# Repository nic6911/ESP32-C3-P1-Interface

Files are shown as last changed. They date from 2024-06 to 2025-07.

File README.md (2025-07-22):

# ESP32-C3-P1-Interface
ESPHome module for P1 port power meter readings for use with Home Assistant.
Code is based on Slimmelezer ESPhome code. Functionality of the module is the same, this is just even more Slim :)

Production data is available - but please respect the license !

If you like then please

"Buy Me A Coffee" (https://bmc.link/nic6911w)

This work is licensed under a  
[Creative Commons Attribution-NonCommercial-ShareAlike 4.0 International License][cc-by-nc-sa].

[][cc-by-nc-sa]

[cc-by-nc-sa]: http://creativecommons.org/licenses/by-nc-sa/4.0/  
[cc-by-nc-sa-image]: https://licensebuttons.net/l/by-nc-sa/4.0/88x31.png  
[cc-by-nc-sa-shield]: https://img.shields.io/badge/License-CC%20BY--NC--SA%204.0-lightgrey.svg

---

## Pictures of the module
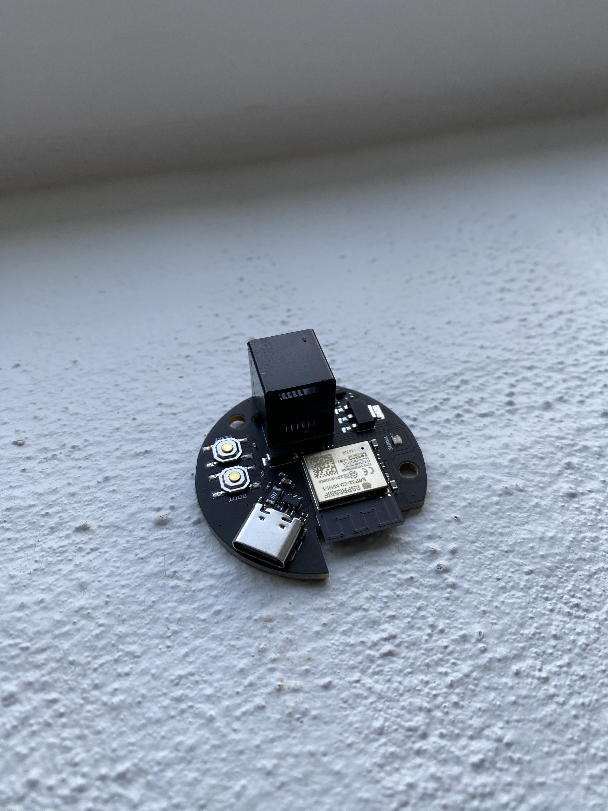
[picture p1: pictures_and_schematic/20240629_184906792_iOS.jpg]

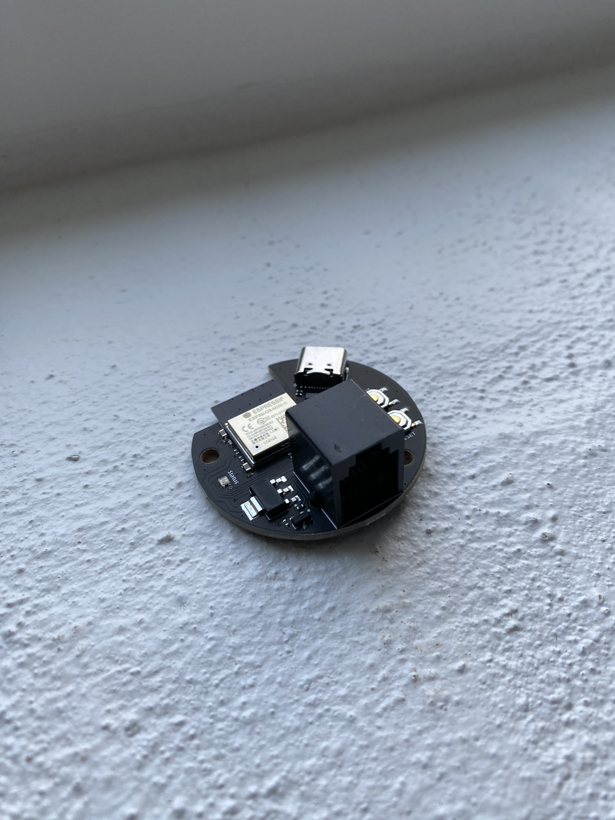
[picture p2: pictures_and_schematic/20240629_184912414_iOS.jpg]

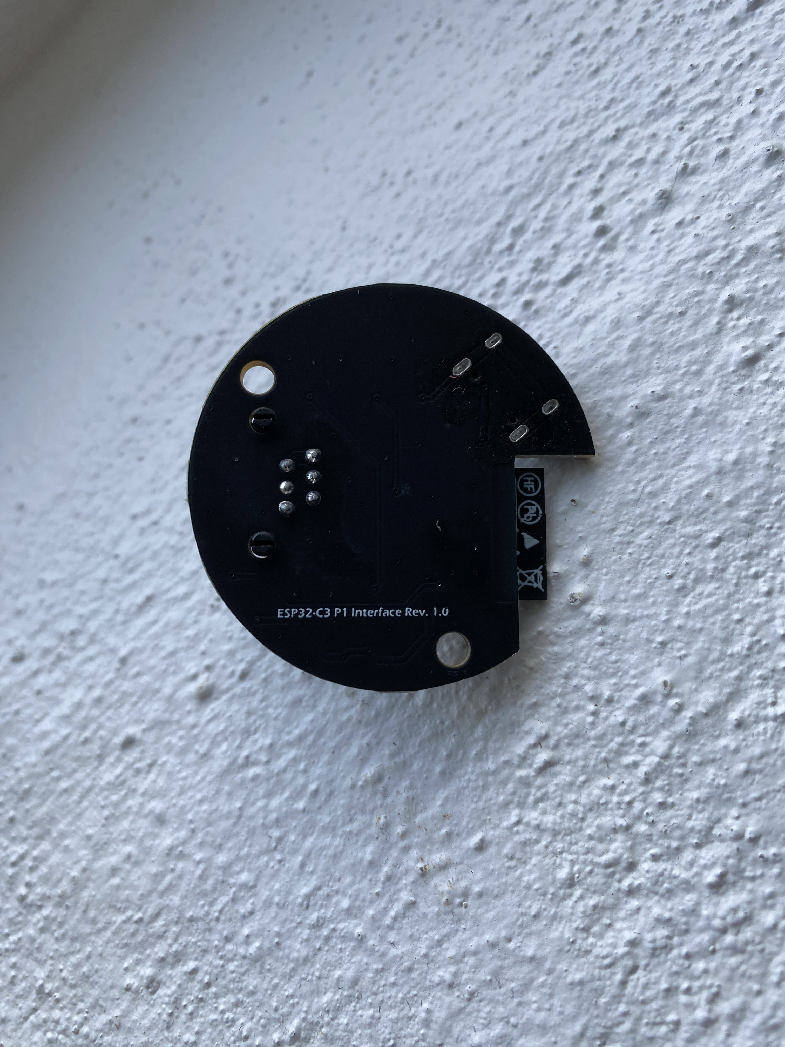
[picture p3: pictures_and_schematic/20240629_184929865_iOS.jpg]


## Schematic of the module
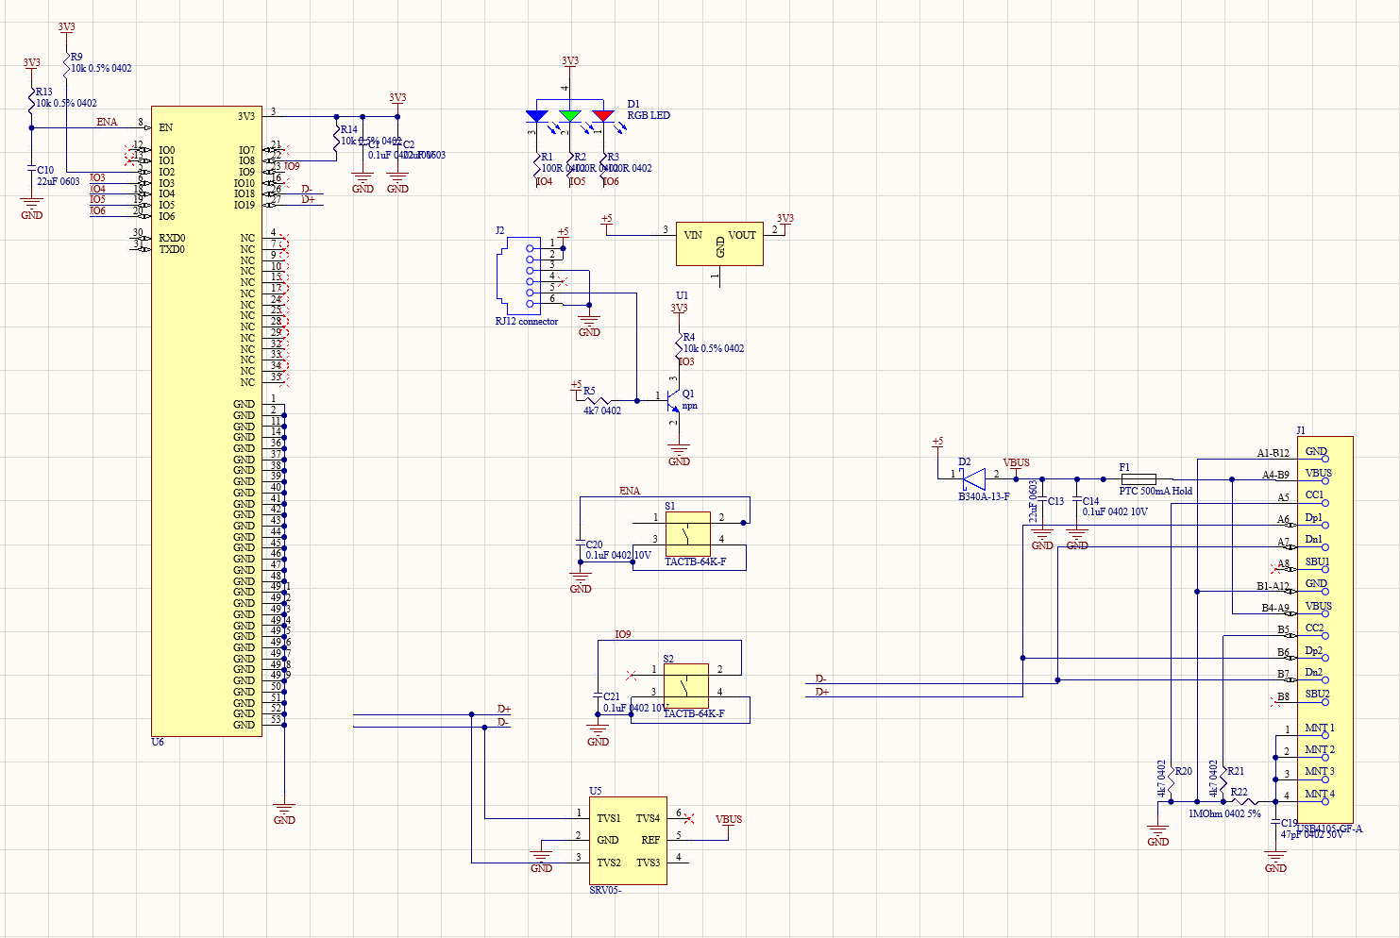
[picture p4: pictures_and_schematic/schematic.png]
Schematic


## Disclaimer
Use at your own risk !

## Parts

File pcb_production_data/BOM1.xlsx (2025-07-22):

Comment | Designator | Footprint | LCSC Part Number
100nF 0402 | C1, C14, C20, C21 | CAP_0402 | C1525
B340A-13-F | D2 | FP-SMA-MFG | C2480
56pF 0402 50V | C19 | CAP_0402 | C1572
22uF | C2, C10, C13 | CAP_0603 | C59461
100ohm 0402 | R1, R2, R3 | RES_0402 | C25076
LDO | U1 | SOT230P700X180-4N | C6186
RJ12 Connector | J2 |  | C77859
10k | R4, R9, R13, R14 | RES_0402 | C25744
SRV05 | U5 | SOT95P280X145 | C85364
PTC 500mA Hold | F1 | PTC Fuse 1206 | C70073
USB-C | J1 | KH-TYPE-C-16P | C709357
RGB LED | D1 | WL-SFCD_0606 | C965840
NPN | Q1 | ONSC-SOT-23-3-318-08_V | C2150
ESP32-C3-MINI-1-N4 | U6 | ESP32-C3-MINI-1-N4-Footprint-1 | C2838502
1M 0402 | R22 | RES_0402 | C26083
4k7 0402 | R5, R20, R21 | RES_0402 | C25900
TACTB-64K-F | S1, S2 | TACTB-64K-F | C318884

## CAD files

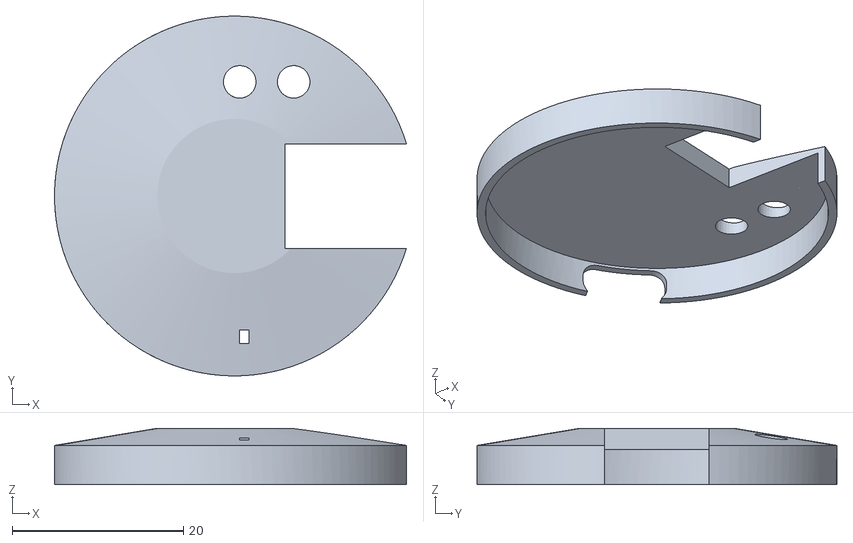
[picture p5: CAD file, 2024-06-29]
3dmodel/top.stl
41.1 x 42.0 x 6.59

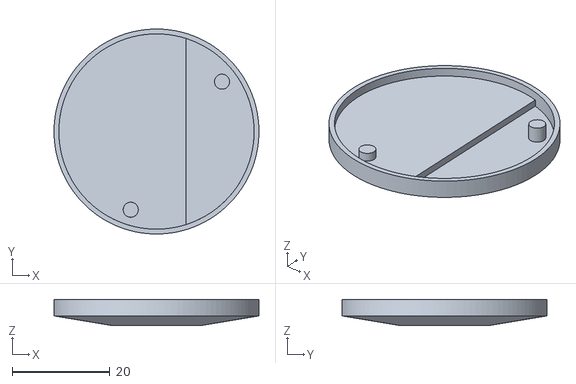
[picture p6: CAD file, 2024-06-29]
3dmodel/bottom.stl
42.0 x 42.0 x 5.41

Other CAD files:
3dmodel/P1C3 cover.f3z

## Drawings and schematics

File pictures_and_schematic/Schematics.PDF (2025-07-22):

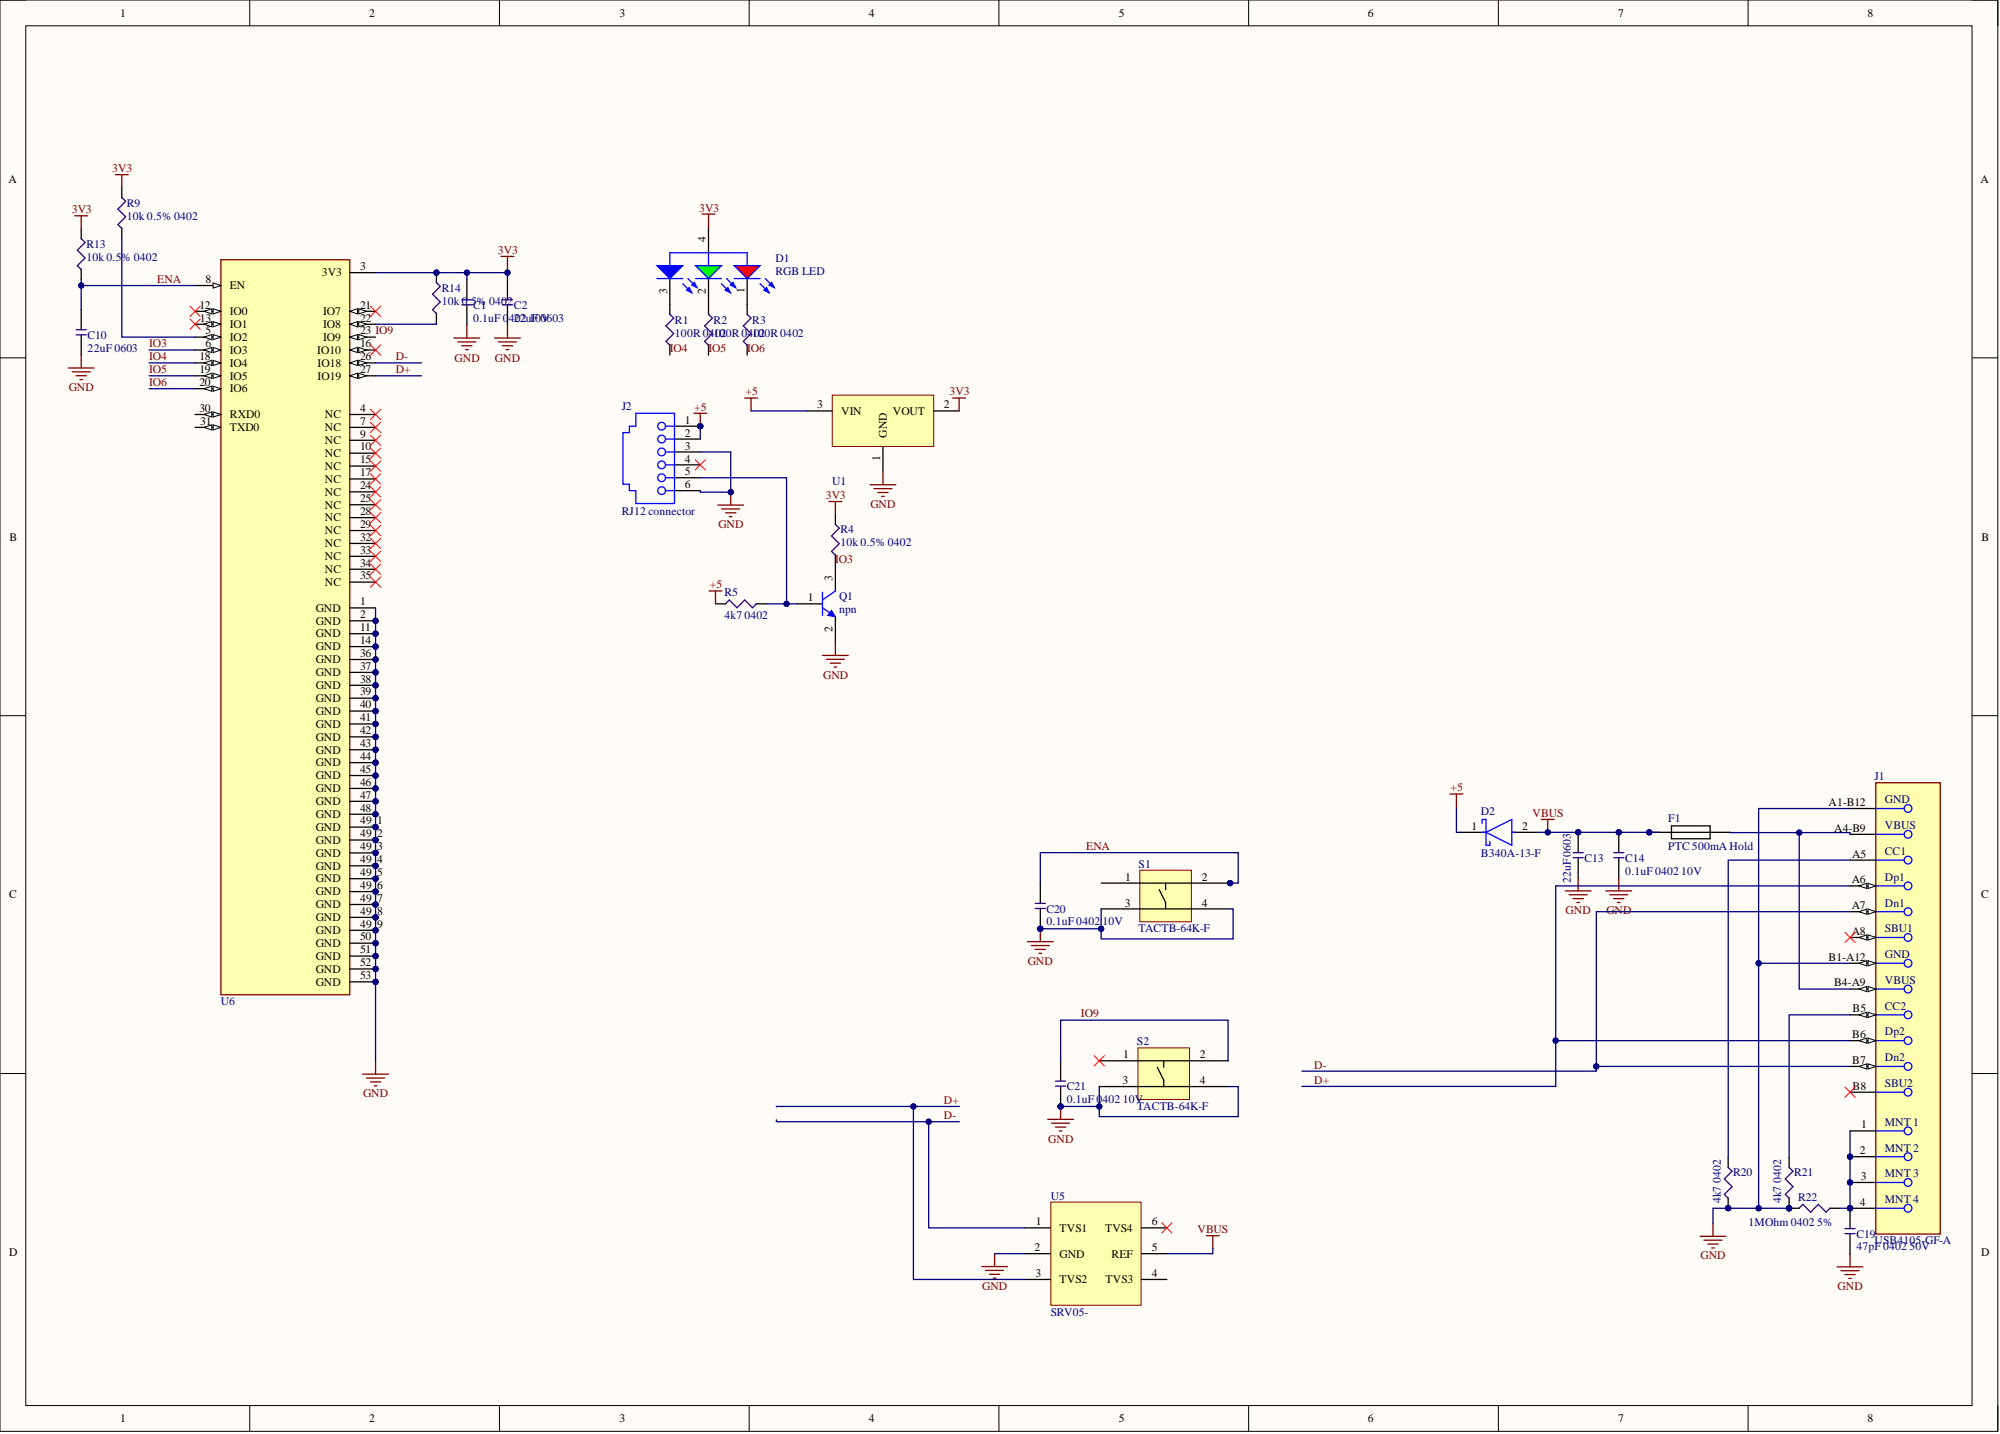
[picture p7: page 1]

1 2
1 3 | 2 2
5 | 2 3

13 | S2TACTB-6

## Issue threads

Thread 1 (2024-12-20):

3D case model without angled edged

exetico, 2024-12-20:
Hi,

Thank you for sharing the design.

Would you be able to make a version of the casing, without the angled edges? I can't really find a good reason to use appx. the same amount on support, instead of just having the design with edged "to the ground" without angled corners.

Or share the Fusion file itself, it it's made in Fusion.

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

That would be much appreciated.

nic6911, 2024-12-23:
I made it like this to look a little more appealing - I printed it the opposite way of what you show here. Support would be internal in the structure to make the outer appearance nice. But I'll add the source file so that you can edit as you like.

exetico, 2024-12-23:
Thank you! Much appreciated.

That's a great amount of work, in that file.

I'll drop the top and bottom without chamfer below.

[Top and Bottom without chamfer.zip](https://github.com/user-attachments/files/18232621/Top.and.Bottom.without.chamfer.zip)

Closed 2024-12-23.

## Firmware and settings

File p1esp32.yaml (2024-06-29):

# Code based on Slimmelezer power meter reader.

esphome:
  name: p1esp32
  friendly_name: P1ESP32
  on_boot:
    then:
      - if:
          condition:
            lambda: return id(has_key);
          then:
            - lambda: |-
                std::string key(id(stored_decryption_key), 32);
                id(dsmr_instance).set_decryption_key(key);
          else:
            - logger.log:
                level: info
                format: "Not using decryption key. If you need to set a key use Home Assistant service 'ESPHome:  ${device_name}_set_dsmr_key'"

substitutions:
  device_name: P1ESP32


esp32:
  board: esp32-c3-devkitm-1
  framework:
    type: arduino  


wifi:
  # remove leading '#' and fill in your wifi details
  ssid: !secret wifi_ssid 
  password: !secret wifi_password
  output_power: "8.5"
  
  # Enable fallback hotspot (captive portal) in case wifi connection fails
  ap:
    ssid: ${device_name}

captive_portal:

# Enable logging
logger:
  baud_rate: 0

# Enable Home Assistant API
api:
  services:
    service: set_dsmr_key
    variables:
      private_key: string
    then:
      - logger.log:
          format: Setting private key %s. Set to empty string to disable
          args: [private_key.c_str()]
      - globals.set:
          id: has_key
          value: !lambda "return private_key.length() == 32;"
      - lambda: |-
          if (private_key.length() == 32)
            private_key.copy(id(stored_decryption_key), 32);
          id(dsmr_instance).set_decryption_key(private_key);

ota:

web_server:
  port: 80

uart:
  baud_rate: 115200
  rx_pin: 3
  rx_buffer_size: 1700

# If you want to use the RGB diode on-board, then use the below
# output:
#   - platform: ledc
#     pin: 4   
#     id: gpio_d4
#     inverted: true
#   - platform: ledc
#     pin: 5
#     id: gpio_d5
#     inverted: true
#   - platform: ledc
#     pin: 6
#     id: gpio_d6  
#     inverted: true

# light:
#   - platform: monochromatic
#     output: gpio_d4
#     name: "Red"
#   - platform: monochromatic
#     output: gpio_d5
#     name: "Blue"
#   - platform: monochromatic
#     output: gpio_d6
#     name: "Green"    


globals:
  - id: has_key
    type: bool
    restore_value: yes
    initial_value: "false"
  - id: stored_decryption_key
    type: char[32]
    restore_value: yes

dsmr:
  id: dsmr_instance
  max_telegram_length: 1700

sensor:
  - platform: dsmr
    energy_delivered_lux:
      name: "Energy Consumed"
    energy_delivered_tariff1:
      name: "Energy Consumed Tariff 1"
    energy_delivered_tariff2:
      name: "Energy Consumed Tariff 2"
    energy_returned_lux:
      name: "Energy Produced"
    energy_returned_tariff1:
      name: "Energy Produced Tariff 1"
    energy_returned_tariff2:
      name: "Energy Produced Tariff 2"
    power_delivered:
      name: "Power Consumed"
      accuracy_decimals: 3
    power_returned:
      name: "Power Produced"
      accuracy_decimals: 3
    electricity_failures:
      name: "Electricity Failures"
      icon: mdi:alert
    electricity_long_failures:
      name: "Long Electricity Failures"
      icon: mdi:alert
    voltage_l1:
      name: "Voltage Phase 1"
    voltage_l2:
      name: "Voltage Phase 2"
    voltage_l3:
      name: "Voltage Phase 3"
    current_l1:
      name: "Current Phase 1"
    current_l2:
      name: "Current Phase 2"
    current_l3:
      name: "Current Phase 3"
    power_delivered_l1:
      name: "Power Consumed Phase 1"
      accuracy_decimals: 3
    power_delivered_l2:
      name: "Power Consumed Phase 2"
      accuracy_decimals: 3
    power_delivered_l3:
      name: "Power Consumed Phase 3"
      accuracy_decimals: 3
    power_returned_l1:
      name: "Power Produced Phase 1"
      accuracy_decimals: 3
    power_returned_l2:
      name: "Power Produced Phase 2"
      accuracy_decimals: 3
    power_returned_l3:
      name: "Power Produced Phase 3"
      accuracy_decimals: 3
  - platform: uptime
    name: "P1ESP32 Uptime"
  - platform: wifi_signal
    name: "P1ESP32 Wi-Fi Signal"
    update_interval: 60s

text_sensor:
  - platform: dsmr
    identification:
      name: "DSMR Identification"
    p1_version:
      name: "DSMR Version"
  - platform: wifi_info
    ip_address:
      name: "P1ESP32 IP Address"
    ssid:
      name: "P1ESP32 Wi-Fi SSID"
    bssid:
      name: "P1ESP32 Wi-Fi BSSID"
  - platform: version
    name: "ESPHome Version"
    hide_timestamp: true

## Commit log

2024-06-29 added pictures, schematic and yaml
2024-06-29 Added 3D step file of module and cover
    Also added STL files for the cover
    [bottom.stl, top.stl]
2024-12-23 fusion 3D file added
    [P1C3 cover.f3z]
2024-12-25 STL without camfer provided by Tobias
2025-07-22 added production data
    [BOM1.xlsx, PickAndPlace1.xlsx]
2025-07-22 pcb source files added

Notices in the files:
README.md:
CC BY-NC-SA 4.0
